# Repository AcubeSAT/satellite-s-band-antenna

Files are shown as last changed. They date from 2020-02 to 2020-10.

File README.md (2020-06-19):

# S-Band Patch Antenna

Design files of S-band patch antenna to be used on board the AcubeSAT are included in the `CST Design Files` folder and test results for the designed antenna are included in the `Anechoic Chamber Tests` folder. A plotter has also been written to plot S11 data taken from CST as a .png with annotations. Can be used to compare measured data with simulations and visualize results in a convenient fashion:

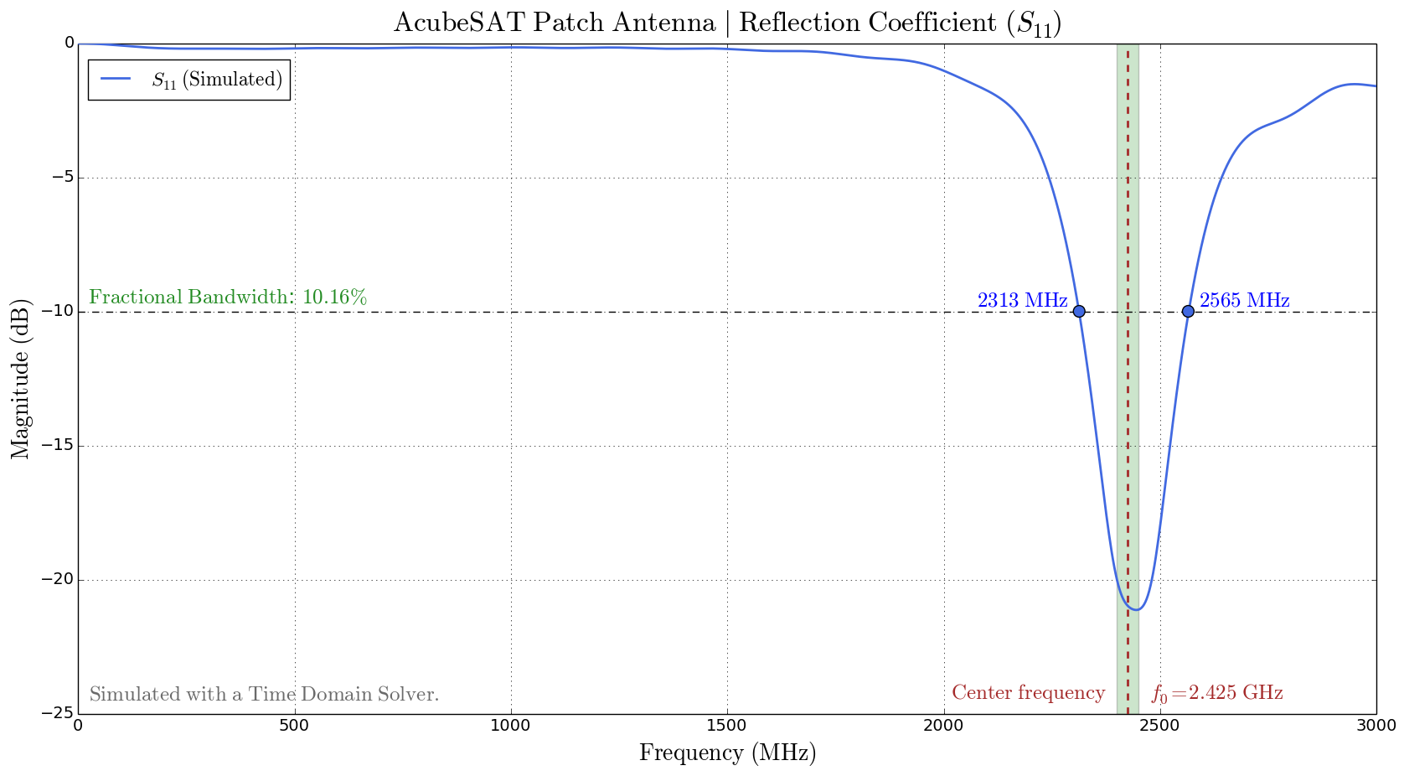
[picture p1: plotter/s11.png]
s11 S11


A plotter has also been written to plot farfield (radiation pattern) data taken from CST as a .png with annotations. Can be used to compare measured data with simulations and visualize results in a convenient fashion:

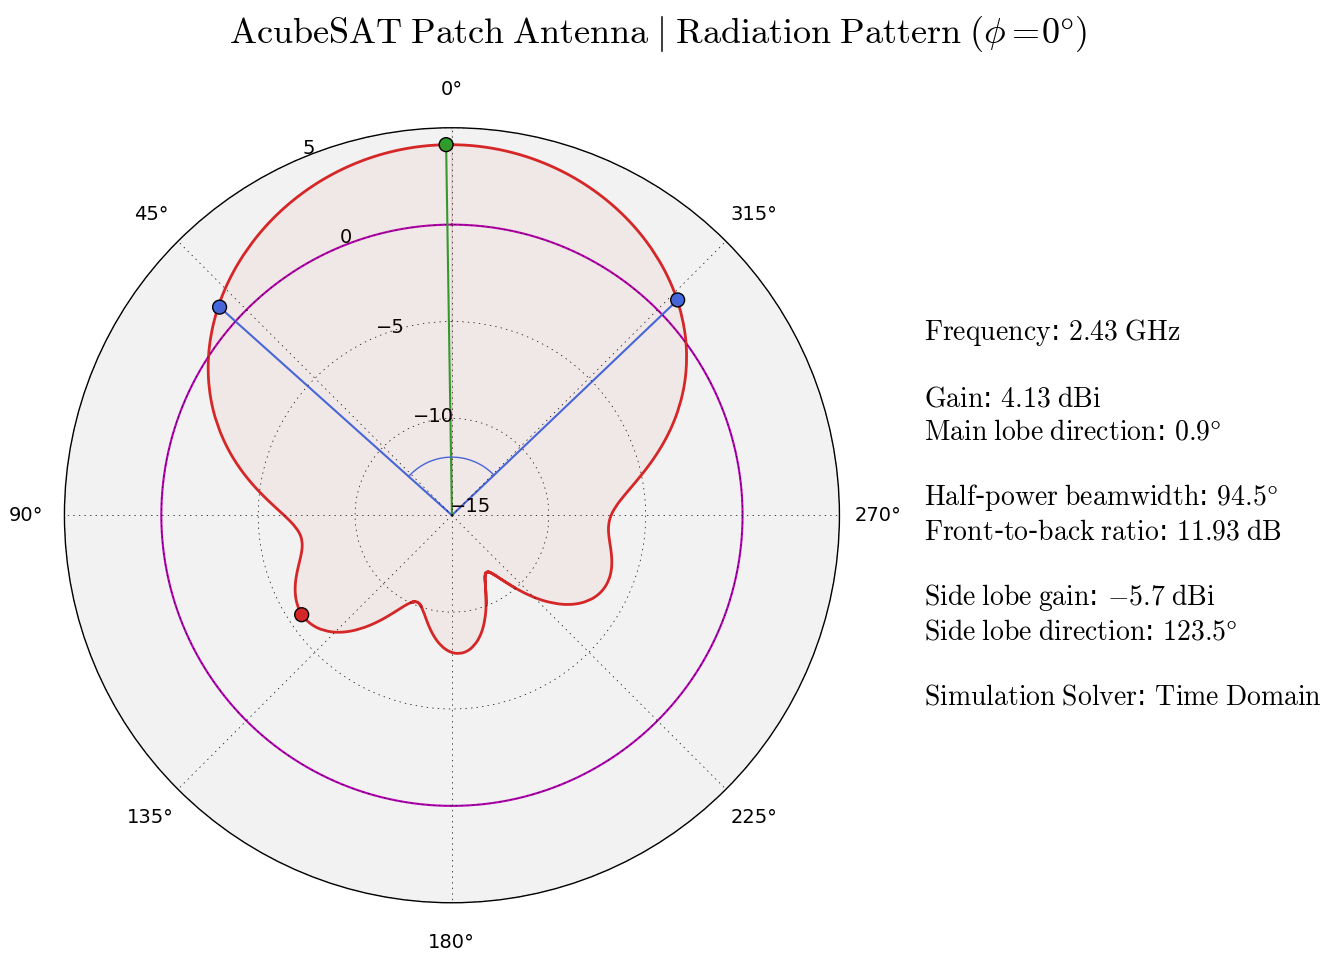
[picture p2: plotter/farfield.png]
farfield Farfield


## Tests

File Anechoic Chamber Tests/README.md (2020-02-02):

# Anechoic Chamber Tests
All the raw data and the test results from the anechoic chamber of the Aristotle University of Thessaloniki can be found here. The U-Slot S-band patch antenna was tested, and two different measurements were done, one getting the antenna pattern and the other calculating the gain in the maximum direction.

## Pattern and Directivity
The raw data of the measurements can be found in the `Raw Data/Antenna Pattern` folder, where there are two `.txt` files containing the angle in the first column and the measured `S21` value in `dB` in the second. The files are delimited with a `tab`. Also, a corresponding MATLAB workspace with the files imported, named `Patch_Antenna_Pattern.mat`, can be found in the `MATLAB Workspaces` folder. There are two files calculating the `directivity` and the `antenna pattern`, one for MATLAB named `directivity_calculation.m` and the other for Jupyter Notebook named `Patch_Antenna_Directivity.ipynb`.

## Gain Measurement With A Reference Standard Gain Horn Antenna
The raw data for the gain can be found in the `Raw Data/Gain Measurement` folder, where the `.txt` files have the frequency of the measurement in the first column and the measured `S21` value in the second. They are delimited by a `tab` and the naming convention is that the direction of the patch and the antenna is denoted after the `S21_horn-` prefix. During this reference measurement the patch antenna was plced on tripod and in the same tripod was placed the [standard gain horn antenna](https://www.atmmicrowave.com/wp-content/uploads/430-440-2_data.pdf) too. Due to the fact of the larger dimensions of the horn antenna, there was a displacement of the face of the horn antenna by **r=29cm** in front of the patch antenna, thus giving slightly higher readings. We compensated for that by calculating the value that we need to deduct from the measurement using the Friis law as follows:
```math
S_{21}^{patch} = G_{patch} + G_{horn} + 20\log\Big(\dfrac{\lambda}{4\pi(D + r)}\Big)
```
```math
S_{21}^{horn} = 2G_{horn} + 20\log\Big(\dfrac{\lambda}{4\pi D}\Big)
```
and the gain for the patch antenna is calculated as:
```math
S_{21}^{patch} - S_{21}^{horn} = G_{patch} - G_{horn} + 20\log\Big(\dfrac{\lambda}{4\pi(D + r)}\Big) - 20\log\Big(\dfrac{\lambda}{4\pi D}\Big) \Rightarrow
```
```math
\Rightarrow G_{patch} = S_{21}^{patch} - S_{21}^{horn} + G_{horn} + 20(\log(D + r) - \log{D})
```
The total distance of the reference horn from the measurement horn was equal to **D=1.4m**. All the required calculations and the final graphs were done in MATLAB and can be found in the file named `gain_calculation.m`, which requires to import the workspace named `gain_data.mat`, from the `MATLAB Workspaces` folder first. Below you can see the rendered preview of the reference calibration measurement antennas. First the reference was measured as seen below

<div align="center">
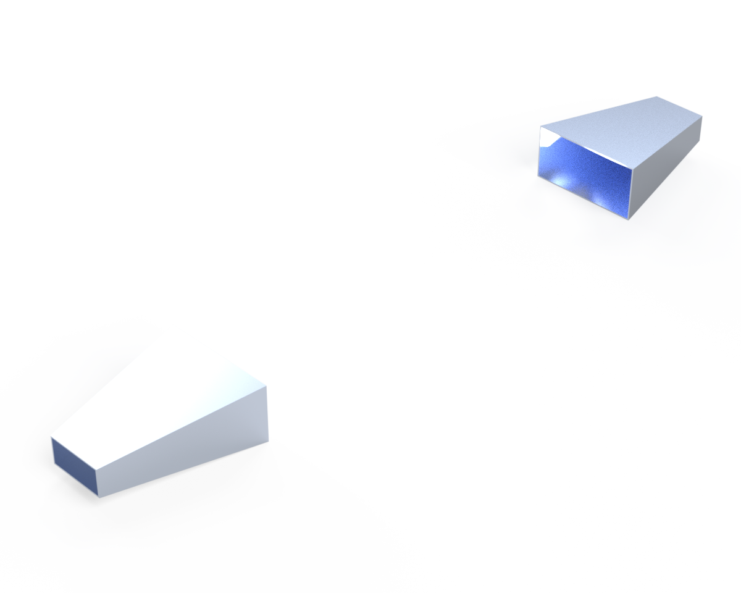
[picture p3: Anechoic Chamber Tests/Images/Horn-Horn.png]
    
</div>

and then the patch antenna in all four directions `Up`, `Right`, `Down` and `Left` was measured.

<div align="center">
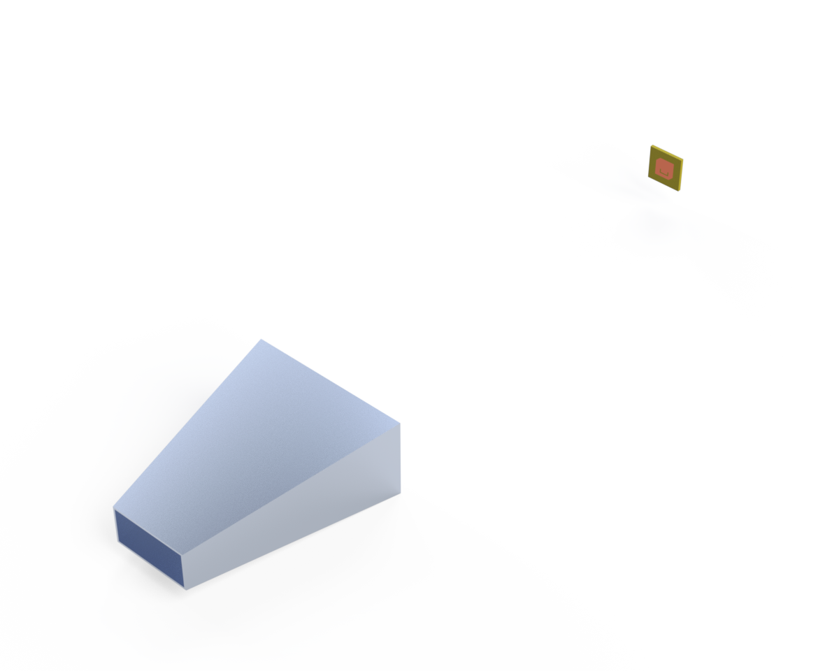
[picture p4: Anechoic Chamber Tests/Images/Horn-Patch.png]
    
</div>

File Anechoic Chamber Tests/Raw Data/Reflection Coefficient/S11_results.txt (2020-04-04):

        Frequency / GHz                S1,1 (5)/abs,dB
----------------------------------------------------------------------
                       1                     -0.10592129
                   1.002                     -0.11040072
               1.0039999                      -0.1145273
                   1.006                     -0.11828604
                   1.008                     -0.12166372
                    1.01                     -0.12464917
                   1.012                       -0.127235
               1.0140001                     -0.12941419
                   1.016                     -0.13118222
                   1.018                     -0.13253752
                    1.02                      -0.1334796
                   1.022                     -0.13401087
                   1.024                     -0.13413558
                   1.026                     -0.13386035
                   1.028                     -0.13319176
                    1.03                     -0.13214135
               1.0319999                     -0.13072154
                   1.034                     -0.12894362
                   1.036                     -0.12682392
                   1.038                     -0.12437822
                    1.04                     -0.12162606
               1.0420001                     -0.11858523
                   1.044                     -0.11527642
                   1.046                     -0.11172074
                   1.048                     -0.10794021
                    1.05                      -0.1039575
                   1.052                    -0.099797033
                   1.054                    -0.095480781
                   1.056                    -0.091035281
                   1.058                    -0.086482998
               1.0599999                    -0.081849153
                   1.062                    -0.077158477
                   1.064                    -0.072435241
                   1.066                    -0.067702918
                   1.068                    -0.062984746
               1.0700001                     -0.05830441
                   1.072                    -0.053685274
                   1.074                    -0.049147739
                   1.076                    -0.044712717
               1.0779999                    -0.040400186
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

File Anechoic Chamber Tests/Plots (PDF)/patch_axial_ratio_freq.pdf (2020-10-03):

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

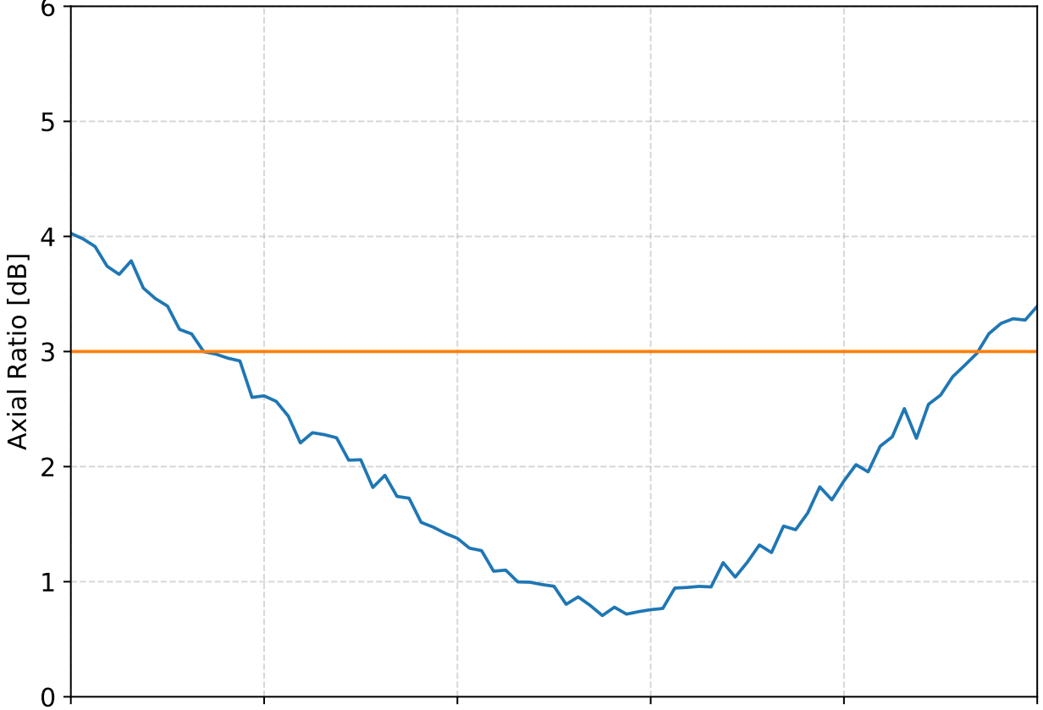
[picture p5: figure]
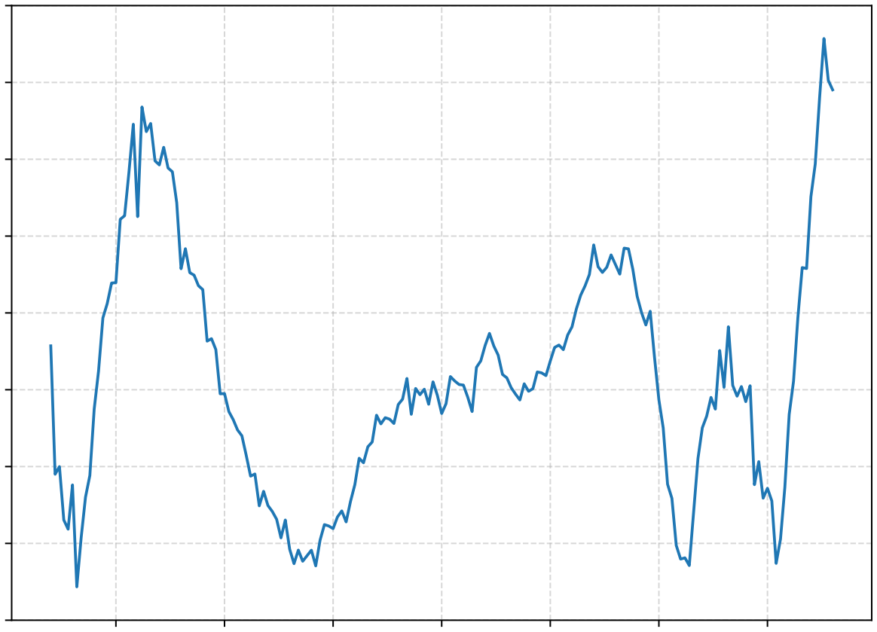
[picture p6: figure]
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

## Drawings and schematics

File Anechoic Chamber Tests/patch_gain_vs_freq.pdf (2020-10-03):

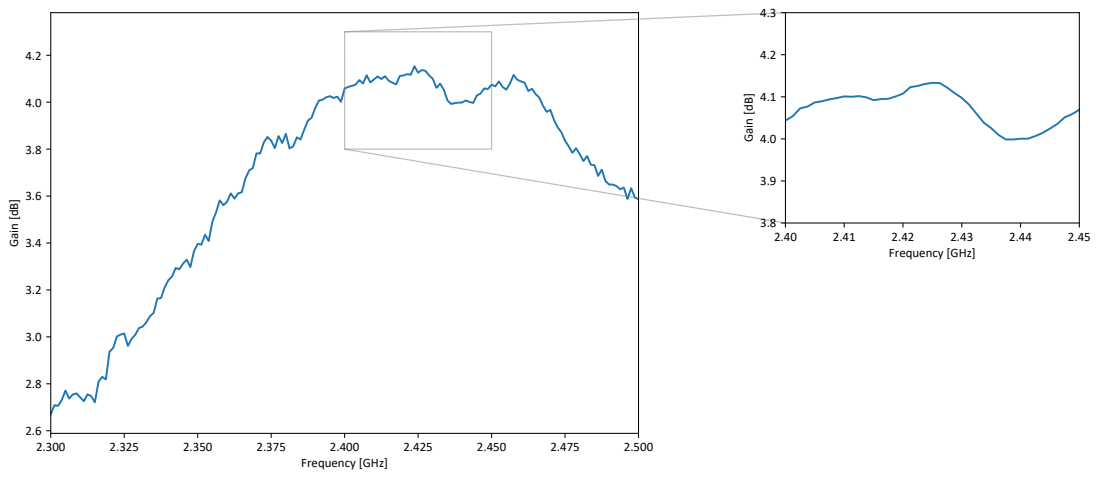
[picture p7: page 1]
Frequency [GHz]; Gain [dB]

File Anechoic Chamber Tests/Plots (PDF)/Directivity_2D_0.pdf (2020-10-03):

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

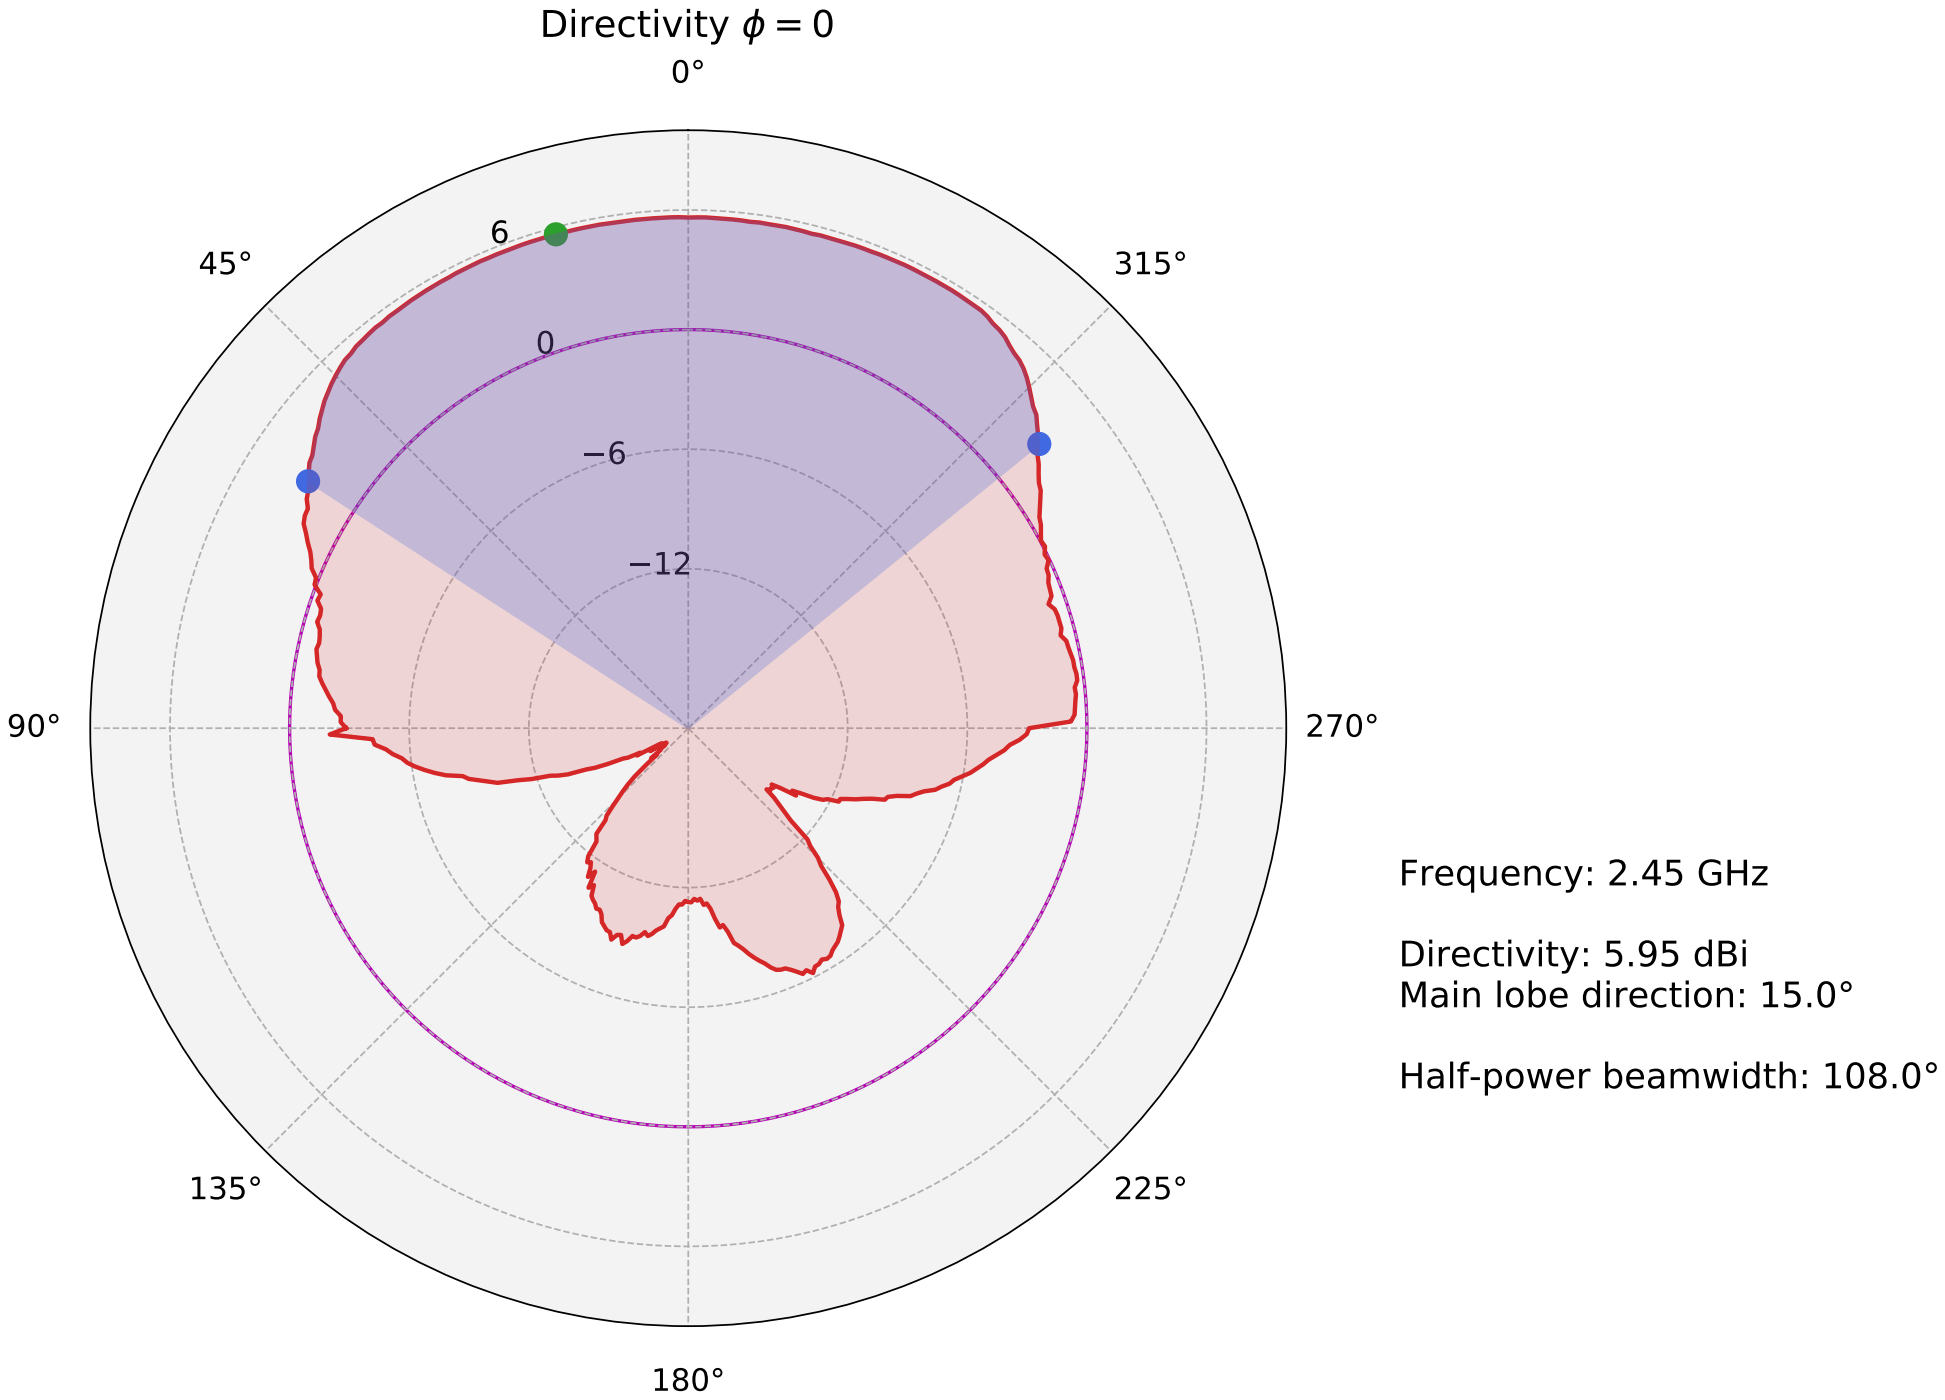
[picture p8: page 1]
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

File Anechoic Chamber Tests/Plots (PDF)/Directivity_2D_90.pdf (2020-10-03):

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

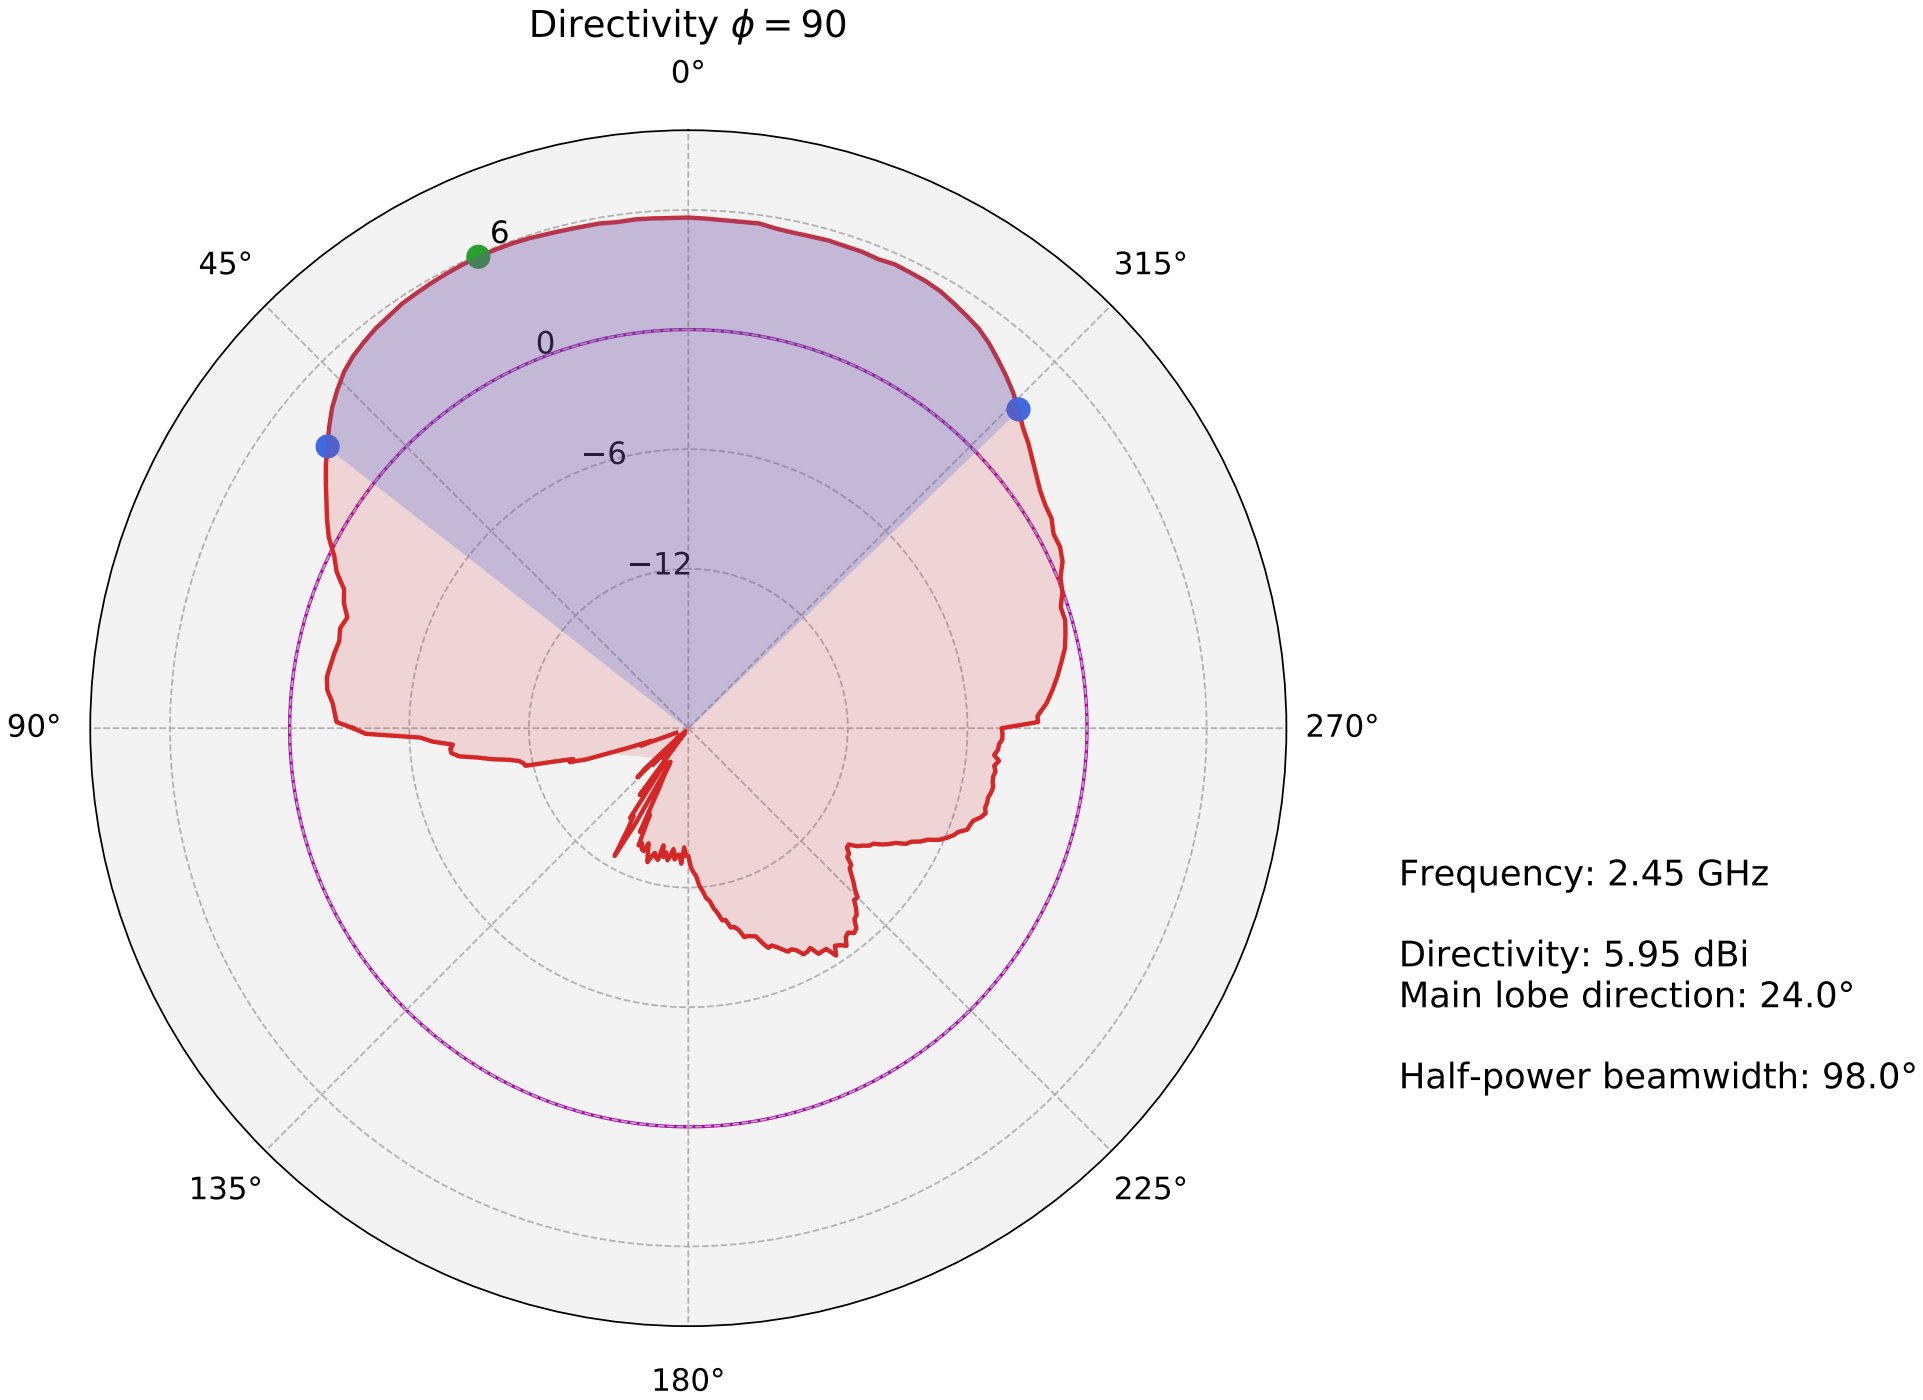
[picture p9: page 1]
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

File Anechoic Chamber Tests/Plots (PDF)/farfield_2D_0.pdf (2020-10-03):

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

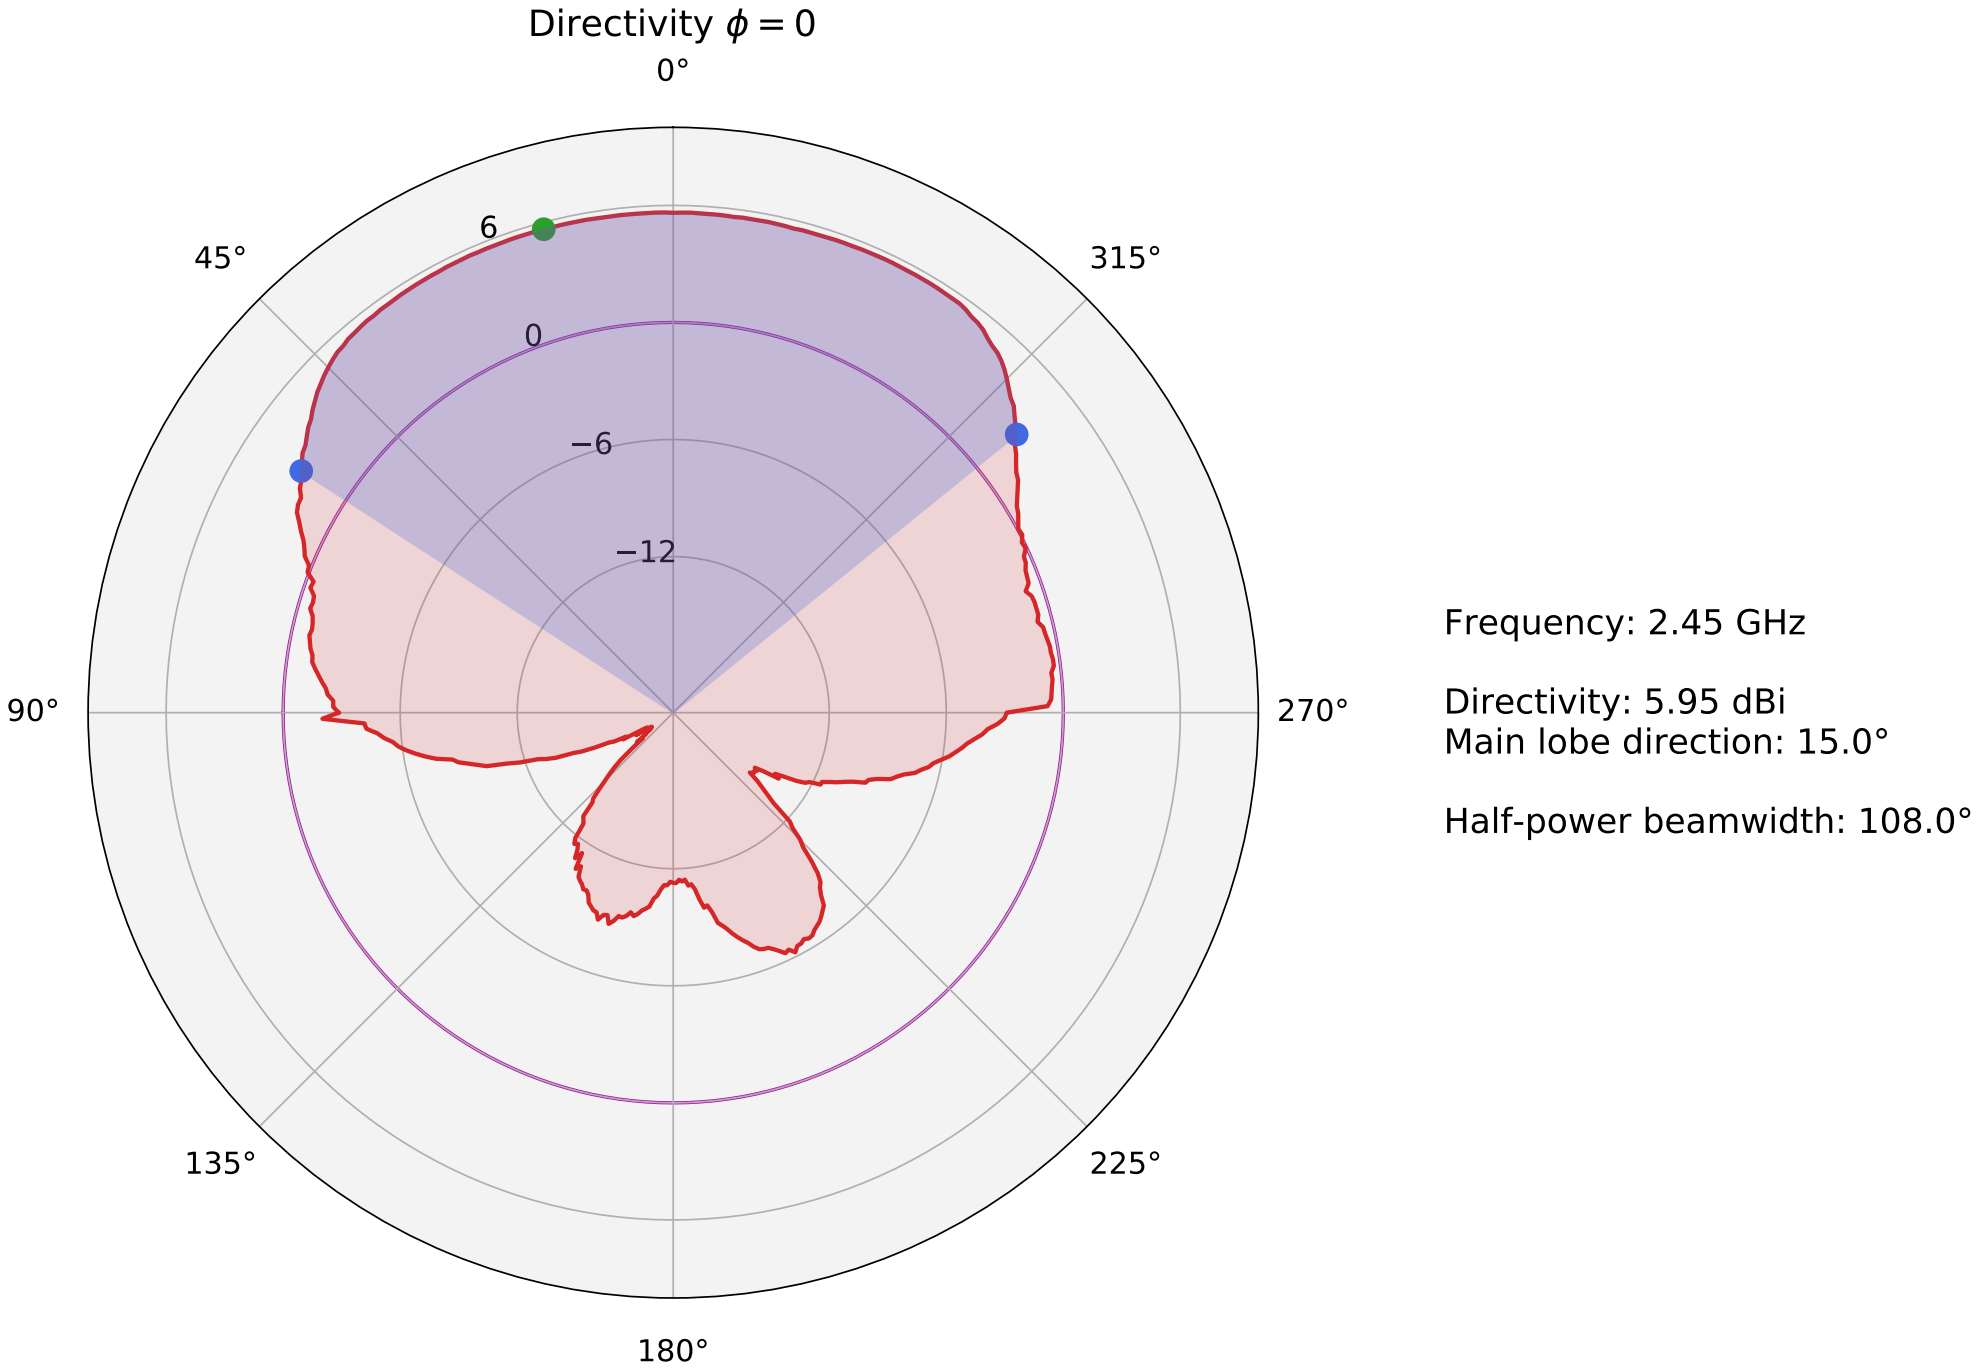
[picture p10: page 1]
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

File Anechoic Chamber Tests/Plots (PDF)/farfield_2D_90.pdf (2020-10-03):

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

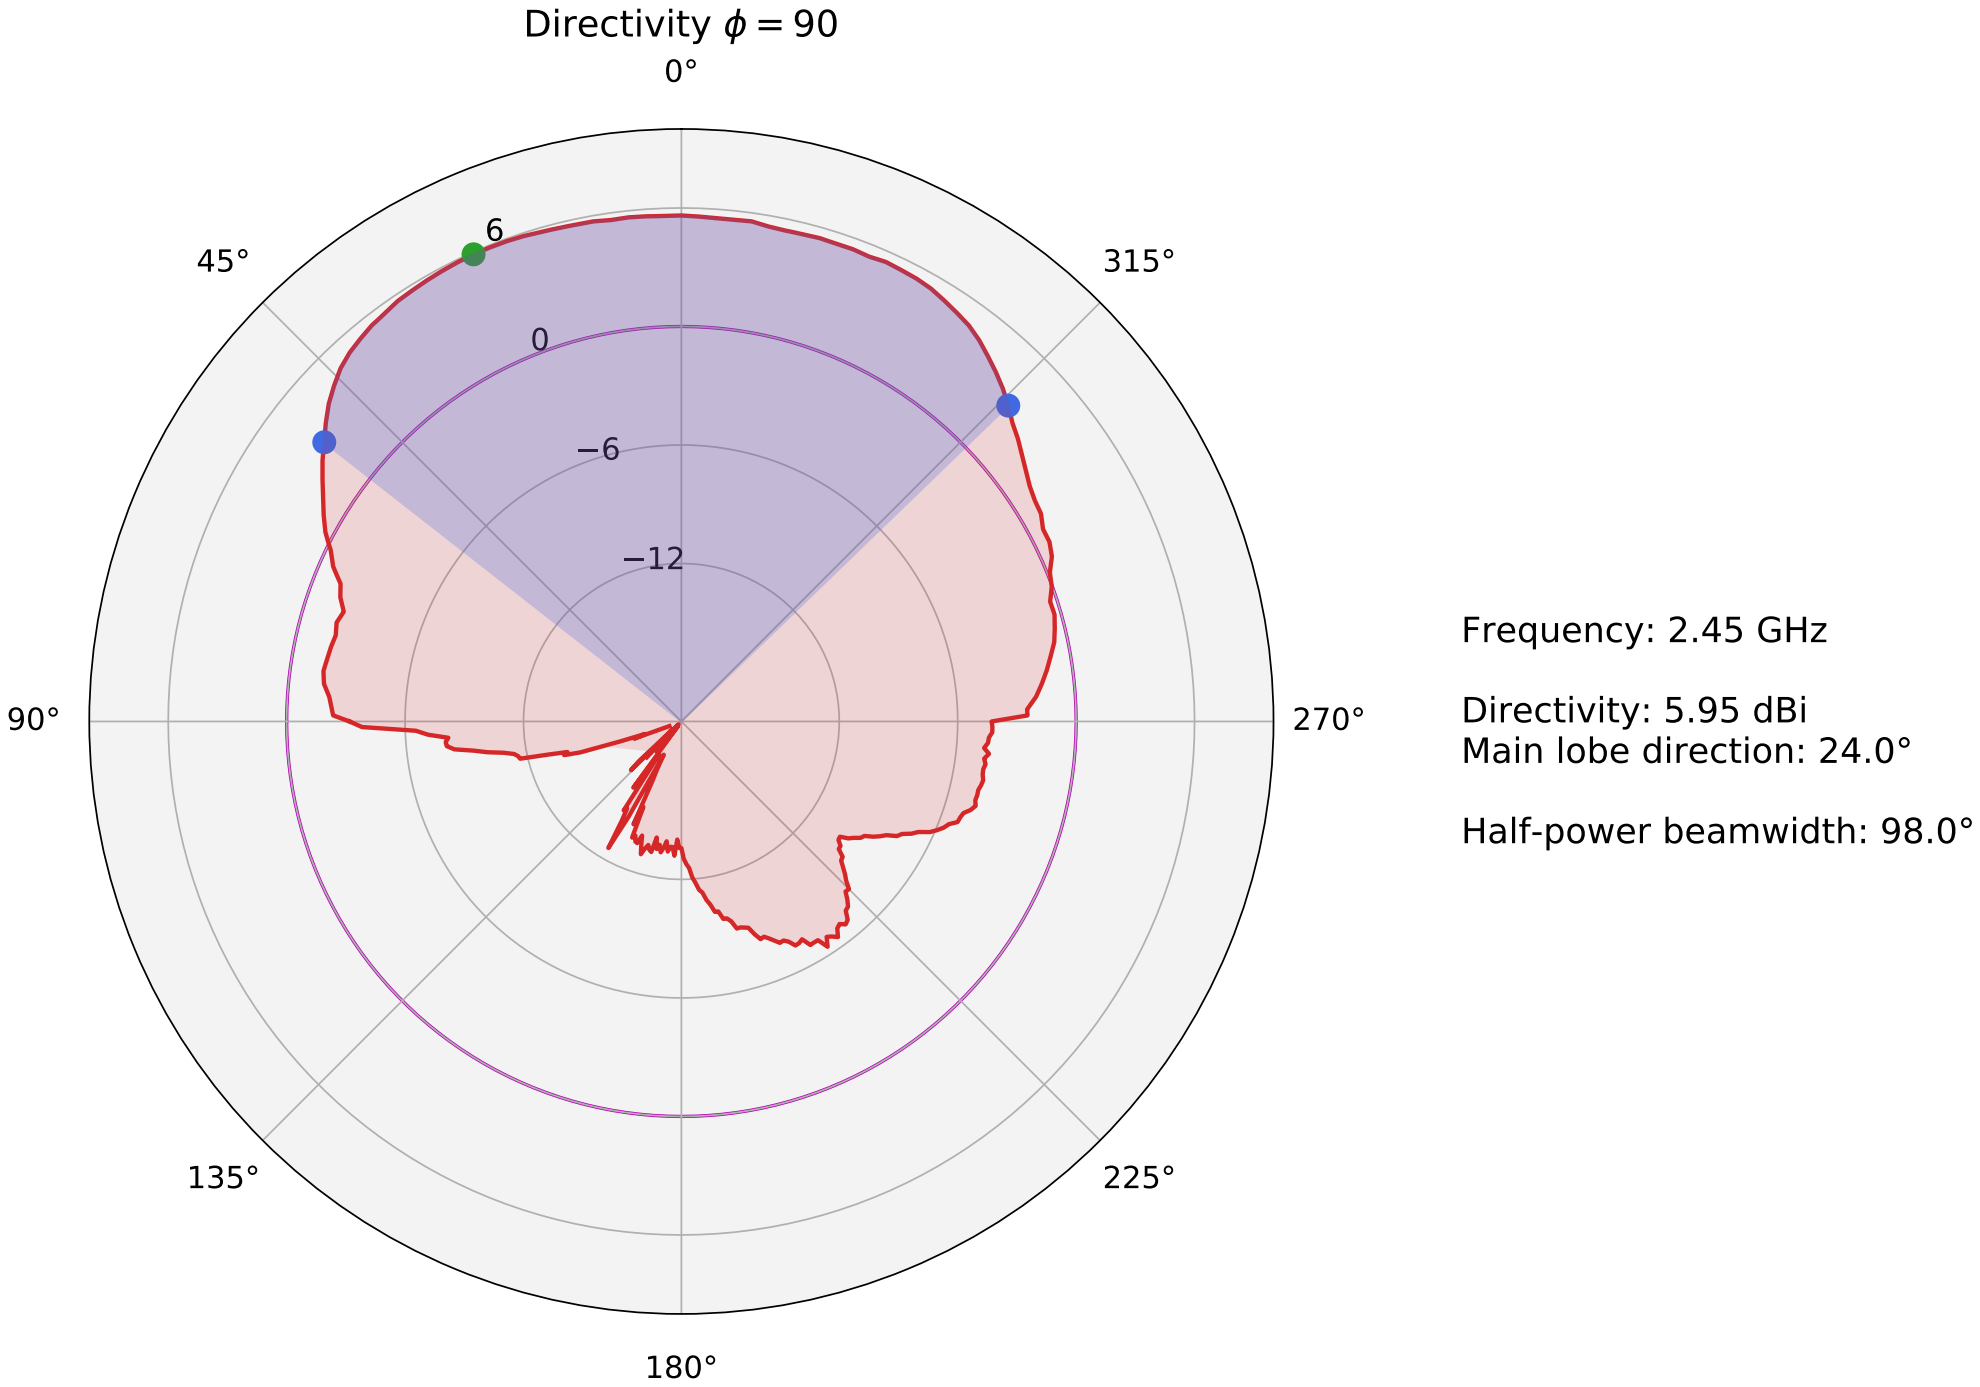
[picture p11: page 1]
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

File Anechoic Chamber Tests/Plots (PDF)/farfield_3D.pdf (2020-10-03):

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

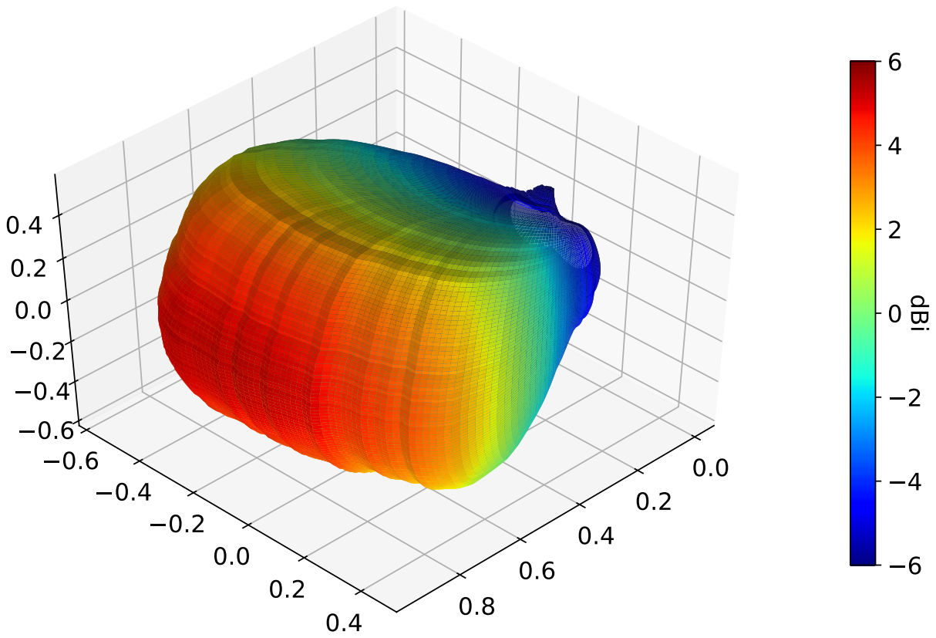
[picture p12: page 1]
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

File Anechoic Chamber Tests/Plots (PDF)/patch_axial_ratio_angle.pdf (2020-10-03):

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

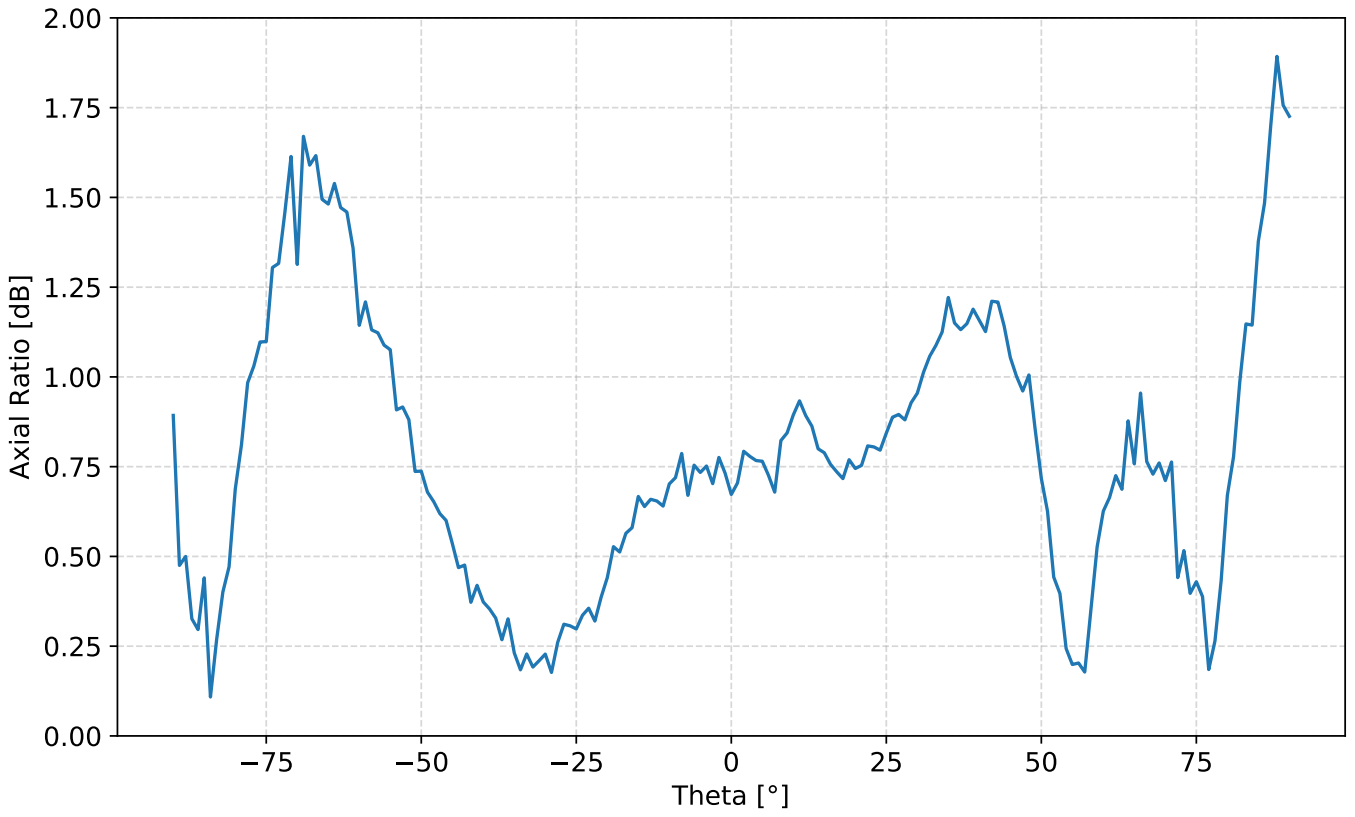
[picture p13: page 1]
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

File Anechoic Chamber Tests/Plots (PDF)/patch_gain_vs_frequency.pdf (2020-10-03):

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

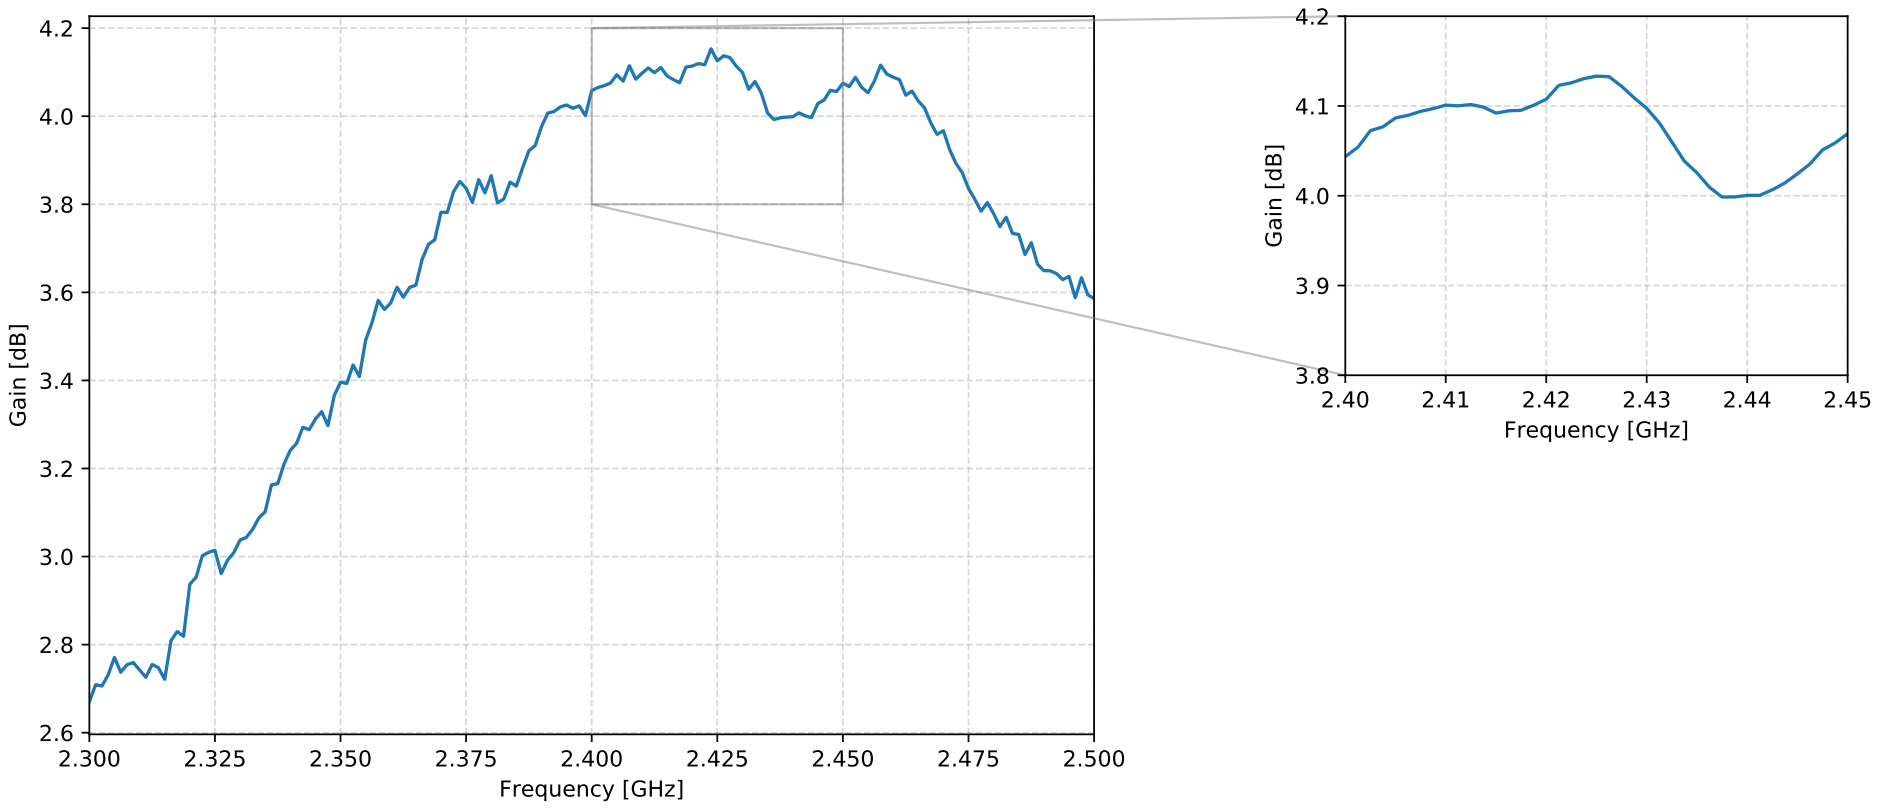
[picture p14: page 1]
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

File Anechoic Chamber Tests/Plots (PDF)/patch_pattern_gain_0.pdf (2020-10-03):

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

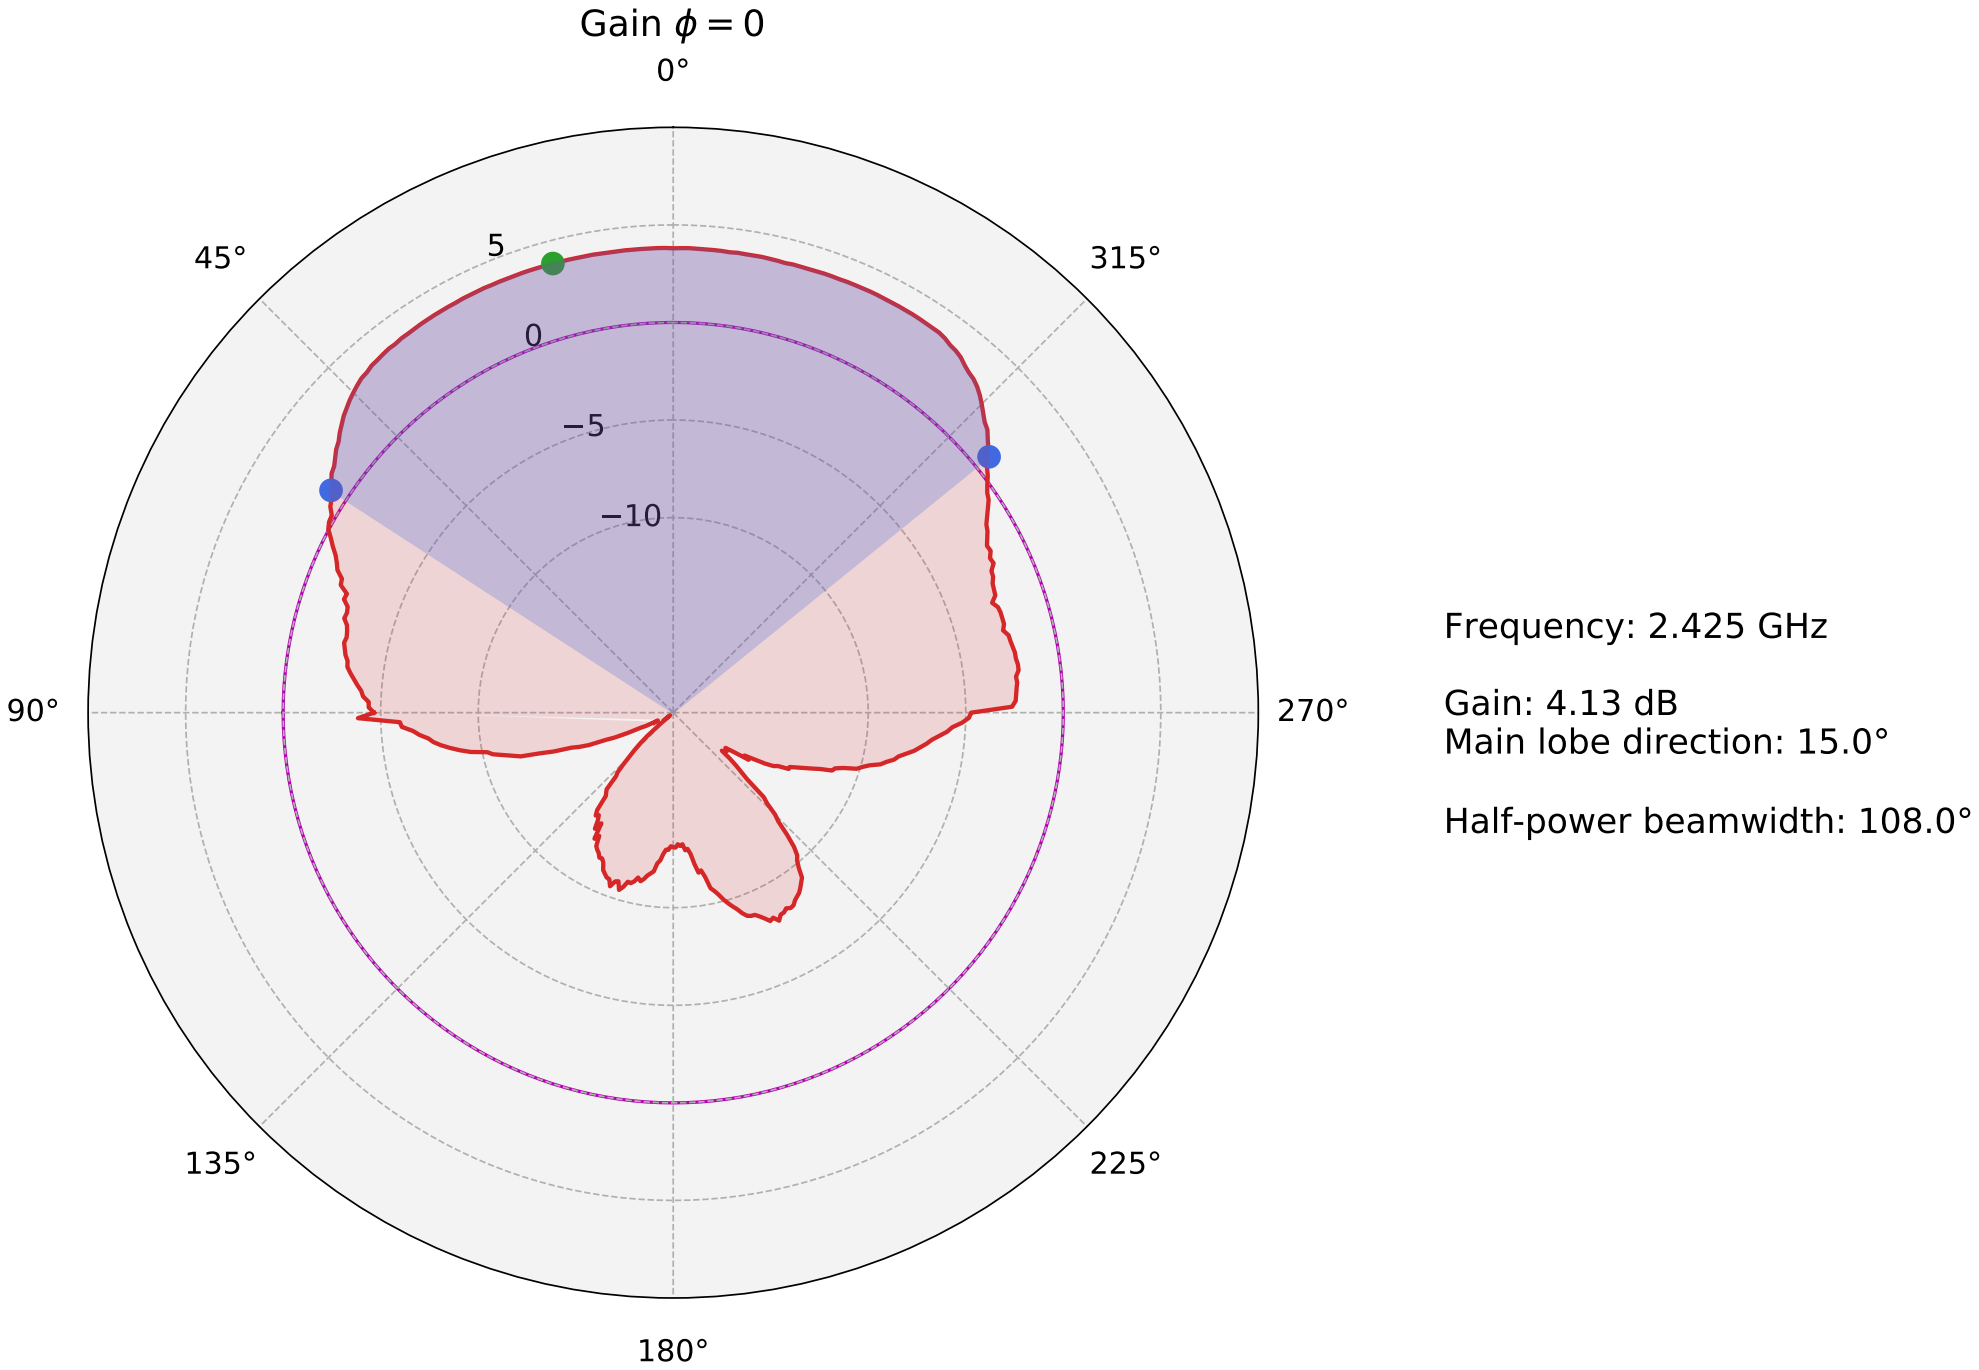
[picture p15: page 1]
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

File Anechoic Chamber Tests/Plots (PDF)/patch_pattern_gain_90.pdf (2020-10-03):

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

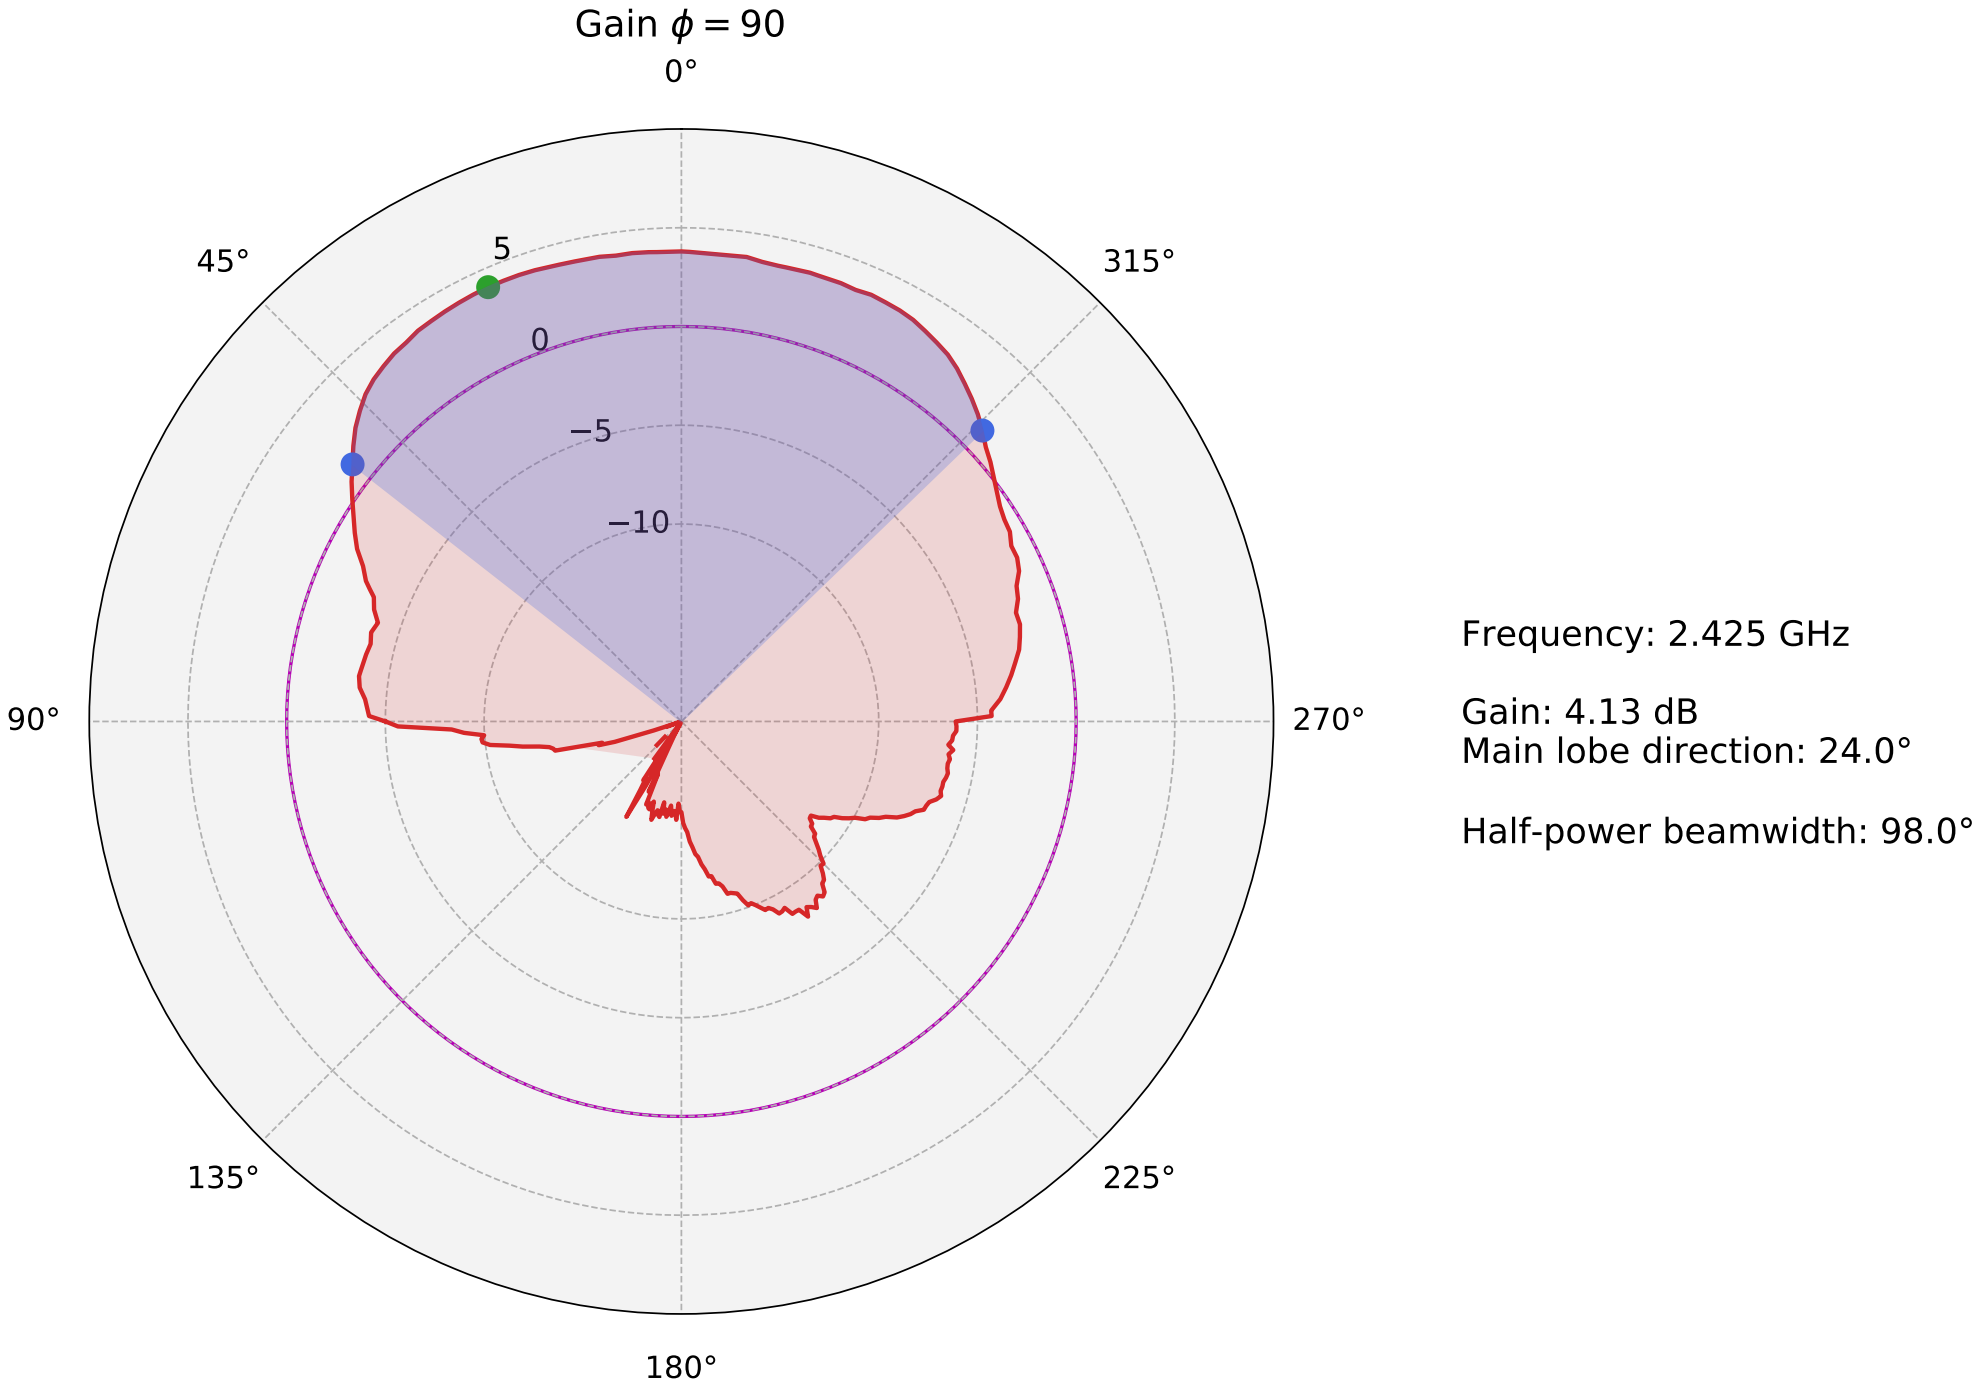
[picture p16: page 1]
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

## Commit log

2019-09-22 Add patch antenna CST
2019-11-24 Change ground and patch material
    From pec to copper
2020-02-02 Added renders of the measurement antennas
2020-02-02 Added antenna renders
2020-03-08 Add new directory for the antenna with the CubeSat structure
2020-03-08 Upload .cst file for patch antenna with structure
2020-03-11 Upload Patch with structure (extended ground plane with screws)
2020-08-28 Relocate screws on patch model for better mechanical support
2020-09-08 Draw the antenna in KiCad to generate gerbers
    [Patch-B_Mask.gbr, Patch-B_Paste.gbr, Patch-B_SilkS.gbr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]
2020-09-09 Patch antenna design transfer finished. Screws to be added
    [Patch-B_Mask.gbr, Patch-B_Paste.gbr, Patch-B_SilkS.gbr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]
2020-09-11 Added screws to the antenna
    [Patch.kicad_pcb]
2020-10-01 Added simulation results for yfeed = 7.66 mm
2020-10-01 Added polarization loss and paramenters
    [patch_polarization_parameters.txt]
2020-10-01 Added one more point in the data
    [patch_polarization_parameters.txt]
2020-10-03 Added the CST design files with python analysis
    [Model.dsn]
